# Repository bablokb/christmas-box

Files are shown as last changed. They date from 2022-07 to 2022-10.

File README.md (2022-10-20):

A Christmas-box with sound and display
======================================

This project is about a Christmas-box, that plays a song and
displays images when the lid is opened:

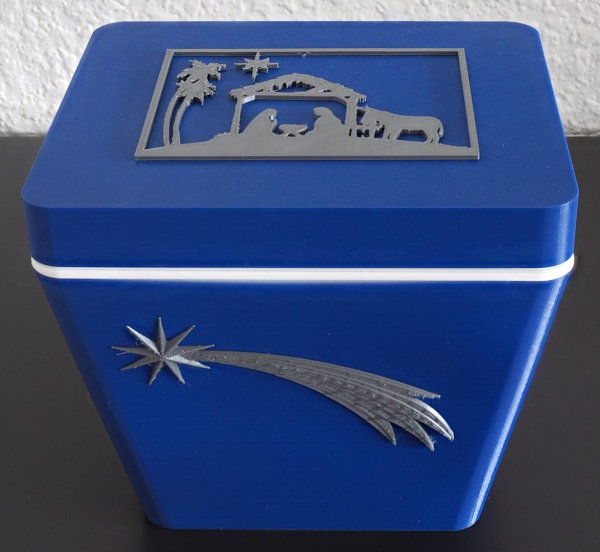
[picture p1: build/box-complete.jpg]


Electronics
-----------

The basis for the electronics is a Raspberry Pi Pico, together
with a small 1.8"-TFT-display and a PAM802A amplifier. The TFT
and the speaker are in the lid, whereas the Pico is inside of
the box.

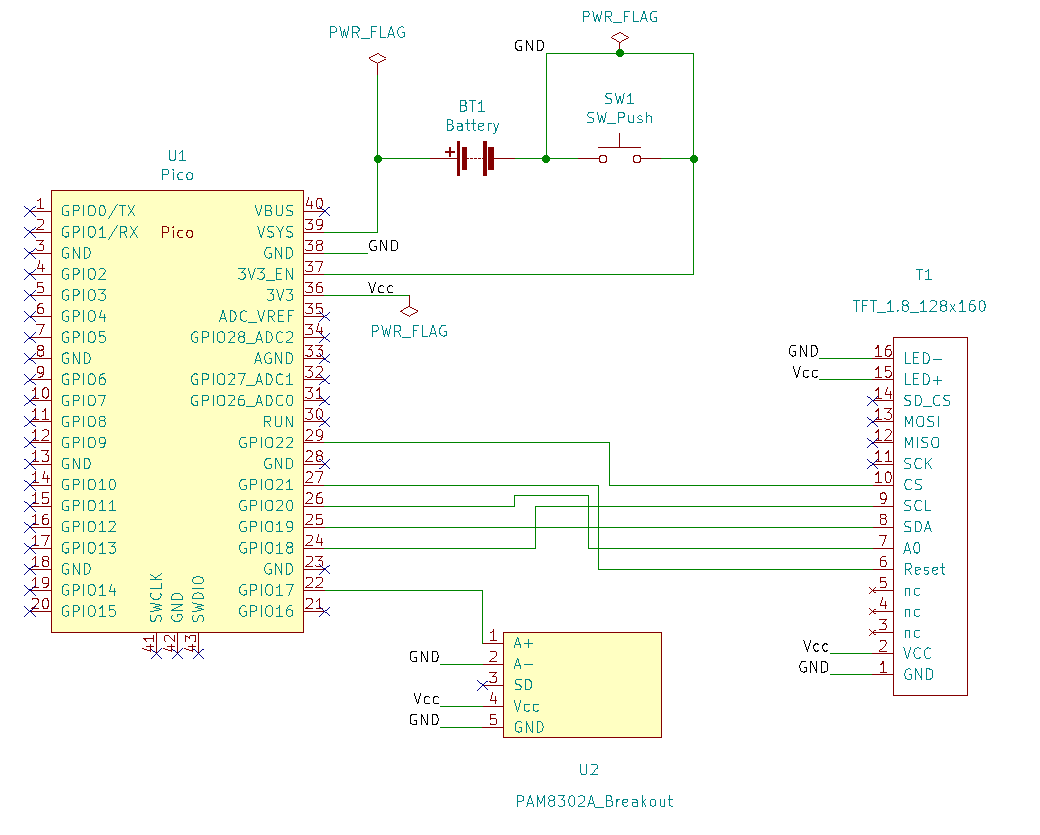
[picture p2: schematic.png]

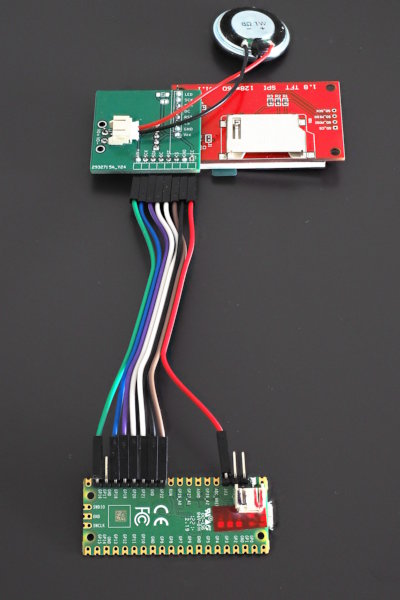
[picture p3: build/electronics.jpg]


(The PAM802A is below the green support PCB).

Software
--------

The Pico runs a small CircuitPython-script that has everything
necessary to display files and to play MP3. The source-code
is in `src/`, some sample media-files are in `src/media/`.

Images must be in BMP-format and the MP3-files are downsampled,
because the Pico does not have enough power to play files with
higher sample-rate.

Build
-----

The box itself was designed using OpenSCAD (source-code in `3D/`).
There is an outer-shell and a smaller inner-shell to make room
for the battery and the Pico:

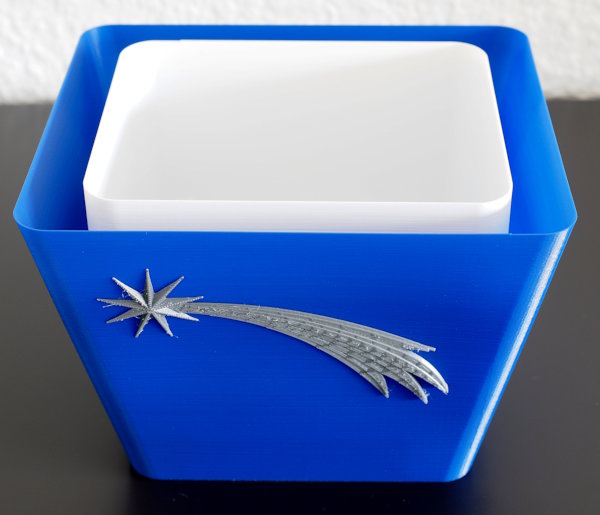
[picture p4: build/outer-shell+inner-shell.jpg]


The lid consists also of two parts:
the outer-part and a frame for the TFT and the speaker.

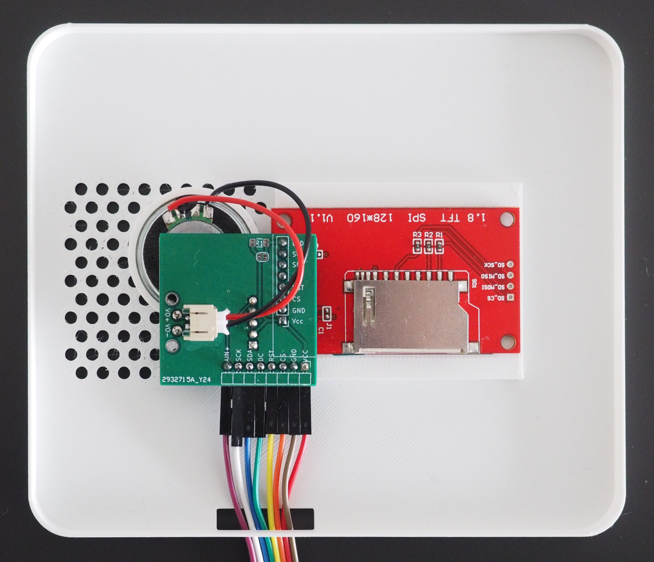
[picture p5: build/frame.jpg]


More images are in the `build/`-directory.

OpenSCAD allows parameters for all dimensions, so you can adjust
the sizes of the parts to your needs without any problems.
Note that I print with tight tolerances, depending on your printer,
you must change this.

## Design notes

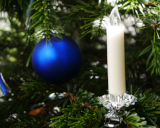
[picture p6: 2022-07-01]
src/media/kugel+kerze.bmp

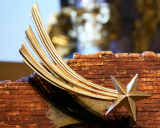
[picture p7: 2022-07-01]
src/media/stern-von-bethlehem.bmp

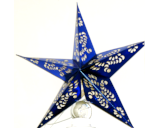
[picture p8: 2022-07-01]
src/media/blauer-stern.bmp

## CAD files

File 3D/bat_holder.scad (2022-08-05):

// -----------------------------------------------------------------------------
// 3D-Model (OpenSCAD) of the battery-holder
//
// Author: Bernhard Bablok
// License: GPL3
//
// https://github.com/bablokb/christmas-box
//
// -----------------------------------------------------------------------------

include <dimensions.scad>

include <BOSL2/std.scad>

module walls() {
  union() {
    translate([0,-y_bat/2,0]) cuboid([2*x_bot,w2,z_bat]);
    translate([0,y_bat/2,0]) cuboid([2*x_bot,w2,z_bat]);
    translate([-x_bat/2,0,0]) cuboid([w2,2*y_bot,z_bat]);
    translate([x_bat/2,0,0]) cuboid([w2,2*y_bot,z_bat]);
  }
}

difference() {
  intersection() {
    translate([0,0,z_bat/2]) walls();
    prismoid(size1=[x_bot-w06,y_bot-w06], 
           size2=[x_top-w06,y_top-w06],
           rounding=10,
           h=z_top+z_b);
  }
  translate([x_bat/2-fuzz,y_bat/2-1.25*c_bat,z_bat/2+c_bat]) cuboid([w2+2*fuzz,c_bat,z_bat]);
  translate([x_bat/2+0.5*(x_bot/2-x_bat/2),-y_bat/2,z_bat/2+c_bat]) cuboid([c_bat,w2+2*fuzz,z_bat]);
}

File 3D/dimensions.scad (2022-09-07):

// -----------------------------------------------------------------------------
// 3D-Model (OpenSCAD) of the christmas-box.
//
// This file defines various dimensions and is included in other scad-scripts.
//
// Author: Bernhard Bablok
// License: GPL3
//
// https://github.com/bablokb/christmas-box
//
// -----------------------------------------------------------------------------

$fa = 1;
$fs = 0.5;
//$fn = 96;

// printer dimensions (walls)

fuzz = 0.01;
gap  = 0.1;
w06 = 0.6;               // vase-mode with wall-thickness 0.6mm
w2  = 0.86;              // 2 walls Prusa MK3S with 0.2mm layer-hight
w4  = 1.67;              // 4 walls Prusa MK3S with 0.2mm layer-hight

// outer shell

x_top = 140;
y_top = 120;
x_del = 18.3;
y_del = 18.3;
x_bot =  x_top - 2*x_del;
y_bot =  y_top - 2*y_del;
z_top =  100;
z_b   =  0.6;            // vase-mode 3 layers
z_lid =  16.5 + z_b;       // inner-hight + base

// inner plate

b_plate = 4.5;
g_leaf  = b_plate - 2.5; // set leaf_gauge of hinges to this value

// hinges

x_hinges     = 30;
y_hinges     =  2;
x_hinges_off = 12;
y_hinges_off = y_top/2 - y_hinges;

// battery dimensions

x_bat = 64.0;
y_bat = 27.0;
z_bat = 19.0;
c_bat = 4.0;     // cutout

// inner shell

x_is = x_bot-w06 + (x_top-x_bot)*(z_bat+z_b)/z_top;  // linear interpolation
y_is = y_bot-w06 + (y_top-y_bot)*(z_bat+z_b)/z_top;  // of dimensions

// frame

x_frame = 100;
y_frame = 60;
b_frame = 0.6;                           // frame-base

// cutout connector

x_conn     = 18;
y_conn     =  5;
x_conn_off = -x_frame/2+55.5;
y_conn_off = y_top/2-w06-w2-y_conn;

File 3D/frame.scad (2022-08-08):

// -----------------------------------------------------------------------------
// 3D-Model (OpenSCAD) of the frame for the display and speaker.
//
// Author: Bernhard Bablok
// License: GPL3
//
// https://github.com/bablokb/christmas-box
//
// -----------------------------------------------------------------------------

include <dimensions.scad>

include <BOSL2/std.scad>

spk_di     = 28.2;                         // speaker, inner diameter
spk_do     = spk_di + 2*w4;                // speaker, outer diameter
spk_off    = 3.0;                          // offset
spk_h      = 4.4;                          // hight

disp_xo     = 58.0;                        // display, outer dimensions
disp_yo     = 46.0;
disp_zo     =  2.9;
disp_off_xo = -(disp_xo+spk_off+spk_do)/2;   // display-offsets
disp_off_yo = -disp_yo/2;

disp_xi     = 44.5;                        // display, innerer dimensions
disp_yi     = 34.2;
disp_zi     =  2.9+b_frame+fuzz;
disp_off_xi = disp_off_xo + 6.9;
disp_off_yi = disp_off_yo + (disp_yo-disp_yi)/2;

disp_pin_x  = 6.9;                         // cutout for display-pins
disp_pin_y  = 23;
disp_pin_z  = 1.3;

spk_grid_x = disp_yo;
spk_grid_y = disp_yo;

// --- supports for display and speaker   ------------------------------------

module supports() {
  cuboid([disp_xo,disp_yo,disp_zo],                    // display-support
          p1=[disp_off_xo,disp_off_yo,b_frame]);   
  translate([disp_off_xo+disp_xo+spk_off+spk_do/2,     // speaker-support
             -(disp_yo-disp_yi)/2,b_frame])
     cylinder(d=spk_do,h=spk_h,center=false);
}

// --- speaker-grid coutouts   -----------------------------------------------

module spk_grid() {
  grid2d(size=[spk_grid_x,spk_grid_y],spacing=5,stagger="alt")
      cylinder(d=3,h=b_frame+fuzz);
}

// --- cutouts for display, speaker, speaker-grid   --------------------------

module cutouts() {
  cuboid([disp_xi,disp_yi,disp_zi],                                  // display
              p1=[disp_off_xi,disp_off_yi,0]);
  cuboid([disp_pin_x,disp_pin_y,disp_pin_z],                         // display-pins
              p1=[disp_off_xi+disp_xi,disp_off_yi+(disp_yi-disp_pin_y)/2,disp_zi-disp_pin_z+fuzz]);
  translate([disp_off_xo+disp_xo+spk_off+spk_di/2+w4,                // speaker
                           -(disp_yo-disp_yi)/2,b_frame])
                   cylinder(d=spk_di,h=spk_h+b_frame+fuzz,center=false);
  translate([disp_off_xo+disp_xo+spk_grid_x/2+spk_off,              // speaker-grid
                           0,0]) spk_grid();
  cuboid([x_conn,y_conn,b_frame+fuzz],
         p1=[x_conn_off,y_conn_off,0]);
}

// --- base-module: plate + wall   --------------------------------------------

module base() {
  prismoid(size1=[x_top,y_top],
           size2=[x_top,y_top],anchor=BOTTOM+CENTER,
           rounding=10,h=b_frame);
  translate([0,0,b_frame]) difference() {
    prismoid(size1=[x_top-2*w06,y_top-2*w06],
             size2=[x_top-2*w06,y_top-2*w06],anchor=BOTTOM+CENTER,
             rounding=10,h=z_lid-z_b-1);
    prismoid(size1=[x_top-2*w06-2*w2,y_top-2*w06-2*w2],
             size2=[x_top-2*w06-2*w2,y_top-2*w06-2*w2],anchor=BOTTOM+CENTER,
             rounding=10,h=z_lid-z_b-1);
  }
}

// --- final frame: base + supports - cutouts   ---------------------------------

module frame() {
  difference() {
    union() {
      base();
      supports();
    }
    cutouts();
  }
}

frame();

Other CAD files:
3D/hinges.scad
3D/inner-plate.scad
3D/inner-shell.scad
3D/lid.scad
3D/pico_holder.scad
3D/shell.scad

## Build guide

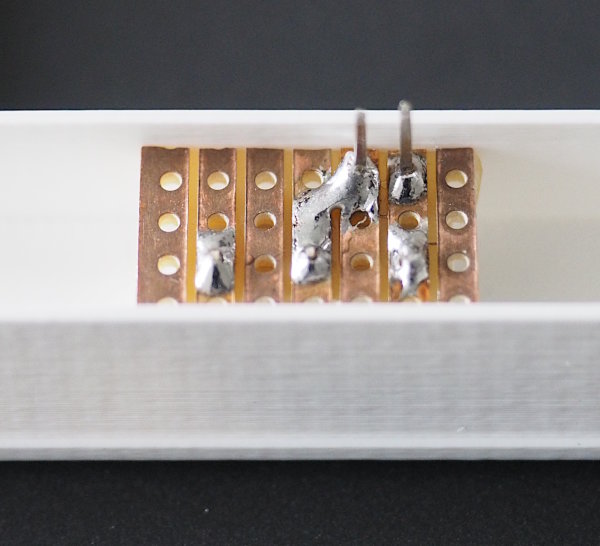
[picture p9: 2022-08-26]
build/button-stripboard.jpg

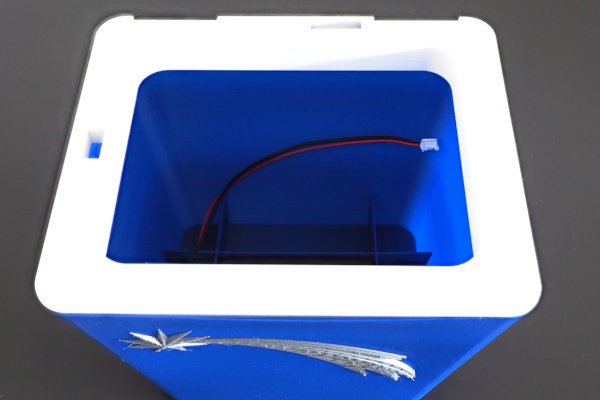
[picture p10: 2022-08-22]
build/outer-shell+inner-plate.jpg

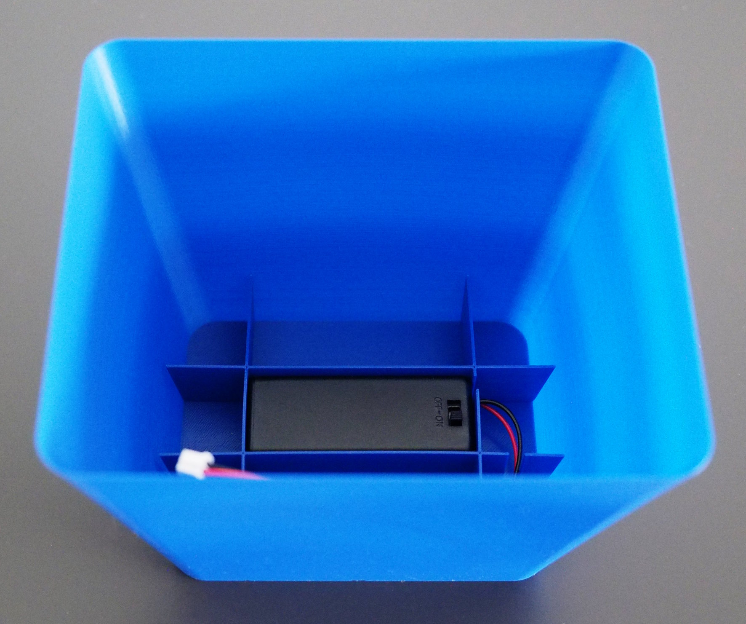
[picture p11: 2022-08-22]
build/outer-shell.jpg

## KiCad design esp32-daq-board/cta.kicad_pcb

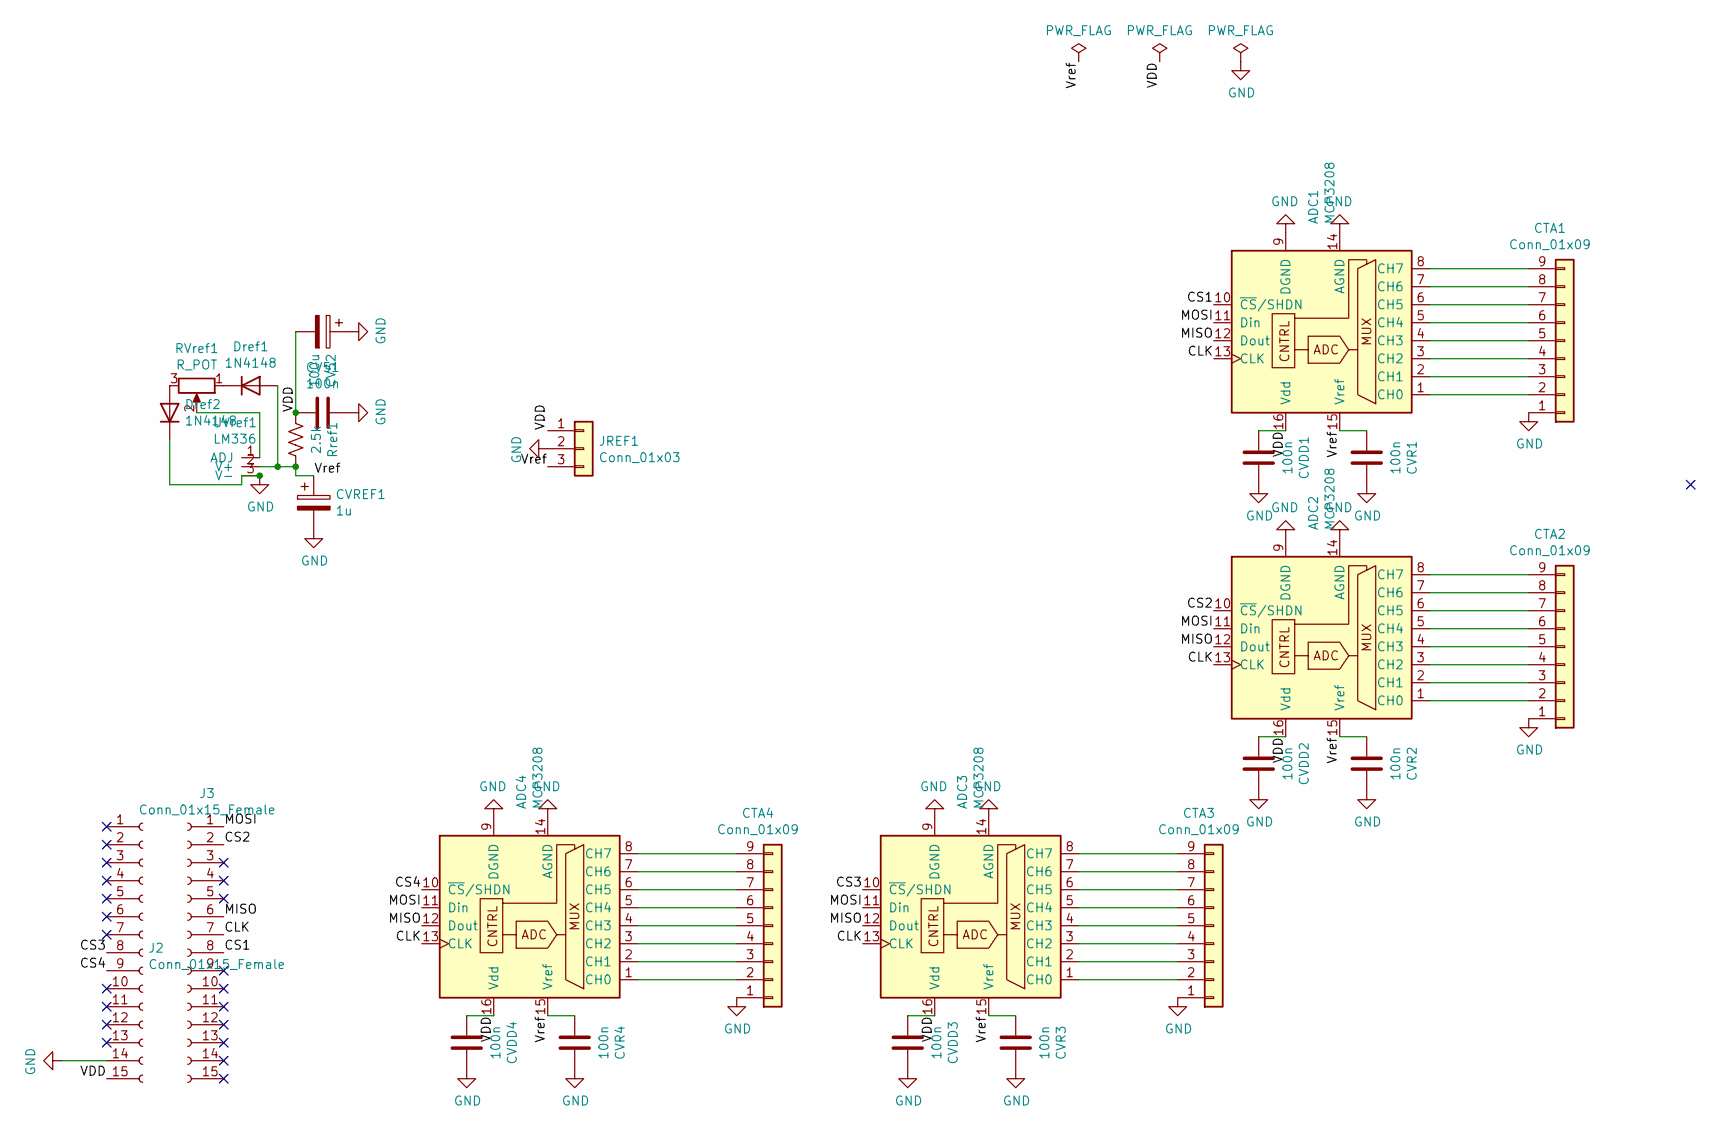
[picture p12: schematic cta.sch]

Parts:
ADC1, ADC2, ADC3, ADC4: MCP3208; DIP-16_W7.62mm_LongPads
CTA1, CTA2, CTA3, CTA4: Conn_01x09; PinHeader_1x09_P2.54mm_Vertical
CV51: 100n; C_Rect_L7.2mm_W3.0mm_P5.00mm_FKS2_FKP2_MKS2_MKP2
CV52: 100u; CP_Radial_D6.3mm_P2.50mm
CVDD1, CVDD2, CVDD3, CVDD4: 100n; C_Rect_L7.2mm_W3.0mm_P5.00mm_FKS2_FKP2_MKS2_MKP2
CVR1, CVR2, CVR3, CVR4: 100n; C_Rect_L7.2mm_W3.0mm_P5.00mm_FKS2_FKP2_MKS2_MKP2
CVREF1: 1u; CP_Radial_D4.0mm_P2.00mm
Dref1, Dref2: 1N4148; D_DO-35_SOD27_P7.62mm_Horizontal
J2, J3: Conn_01x15_Female; PinSocket_1x15_P2.54mm_Vertical
JREF1: Conn_01x03; TerminalBlock_bornier-3_P5.08mm
RVref1: R_POT; Potentiometer_Bourns_3296W_Vertical
Rref1: 2.5k; R_Axial_DIN0207_L6.3mm_D2.5mm_P10.16mm_Horizontal
UVref1: LM336; TO-92L_Inline_Wide

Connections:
/CLK: ADC1.13 (CLK), ADC2.13 (CLK), ADC3.13 (CLK), ADC4.13 (CLK), J3.7
/CS1: ADC1.10 (~CS~/SHDN), J3.8
/CS2: ADC2.10 (~CS~/SHDN), J3.2
/CS3: ADC3.10 (~CS~/SHDN), J2.8
/CS4: ADC4.10 (~CS~/SHDN), J2.9
/MISO: ADC1.12 (Dout), ADC2.12 (Dout), ADC3.12 (Dout), ADC4.12 (Dout), J3.6
/MOSI: ADC1.11 (Din), ADC2.11 (Din), ADC3.11 (Din), ADC4.11 (Din), J3.1
/VDD: ADC1.16 (Vdd), ADC2.16 (Vdd), ADC3.16 (Vdd), ADC4.16 (Vdd), CV51.2, CV52.2, CVDD1.2, CVDD2.2, CVDD3.2, CVDD4.2, J2.15, JREF1.1, Rref1.2
/Vref: ADC1.15 (Vref), ADC2.15 (Vref), ADC3.15 (Vref), ADC4.15 (Vref), CVR1.2, CVR2.2, CVR3.2, CVR4.2, CVREF1.1, Dref1.2 (A), JREF1.3, Rref1.1, UVref1.2 (V+)
GND: ADC1.9 (DGND), ADC1.14 (AGND), ADC2.9 (DGND), ADC2.14 (AGND), ADC3.9 (DGND), ADC3.14 (AGND), ADC4.9 (DGND), ADC4.14 (AGND), CTA1.1, CTA2.1, CTA3.1, CTA4.1, CV51.1, CV52.1, CVDD1.1, CVDD2.1, CVDD3.1, CVDD4.1, CVR1.1, CVR2.1, CVR3.1, CVR4.1, CVREF1.2, Dref2.1 (K), J2.14, JREF1.2, UVref1.3 (V-)
unnamed: ADC1.1 (CH0), CTA1.2
unnamed: ADC1.2 (CH1), CTA1.3
unnamed: ADC1.3 (CH2), CTA1.4
unnamed: ADC1.4 (CH3), CTA1.5
unnamed: ADC1.5 (CH4), CTA1.6
unnamed: ADC1.6 (CH5), CTA1.7
unnamed: ADC1.7 (CH6), CTA1.8
unnamed: ADC1.8 (CH7), CTA1.9
unnamed: ADC2.1 (CH0), CTA2.2
unnamed: ADC2.2 (CH1), CTA2.3
unnamed: ADC2.3 (CH2), CTA2.4
unnamed: ADC2.4 (CH3), CTA2.5
unnamed: ADC2.5 (CH4), CTA2.6
unnamed: ADC2.6 (CH5), CTA2.7
unnamed: ADC2.7 (CH6), CTA2.8
unnamed: ADC2.8 (CH7), CTA2.9
unnamed: ADC3.1 (CH0), CTA3.2
unnamed: ADC3.2 (CH1), CTA3.3
unnamed: ADC3.3 (CH2), CTA3.4
unnamed: ADC3.4 (CH3), CTA3.5
unnamed: ADC3.5 (CH4), CTA3.6
unnamed: ADC3.6 (CH5), CTA3.7
unnamed: ADC3.7 (CH6), CTA3.8
unnamed: ADC3.8 (CH7), CTA3.9
unnamed: ADC4.1 (CH0), CTA4.2
unnamed: ADC4.2 (CH1), CTA4.3
unnamed: ADC4.3 (CH2), CTA4.4
unnamed: ADC4.4 (CH3), CTA4.5
unnamed: ADC4.5 (CH4), CTA4.6
unnamed: ADC4.6 (CH5), CTA4.7
unnamed: ADC4.7 (CH6), CTA4.8
unnamed: ADC4.8 (CH7), CTA4.9
unnamed: Dref1.1 (K), RVref1.1
unnamed: Dref2.2 (A), RVref1.3
unnamed: RVref1.2, UVref1.1 (ADJ)

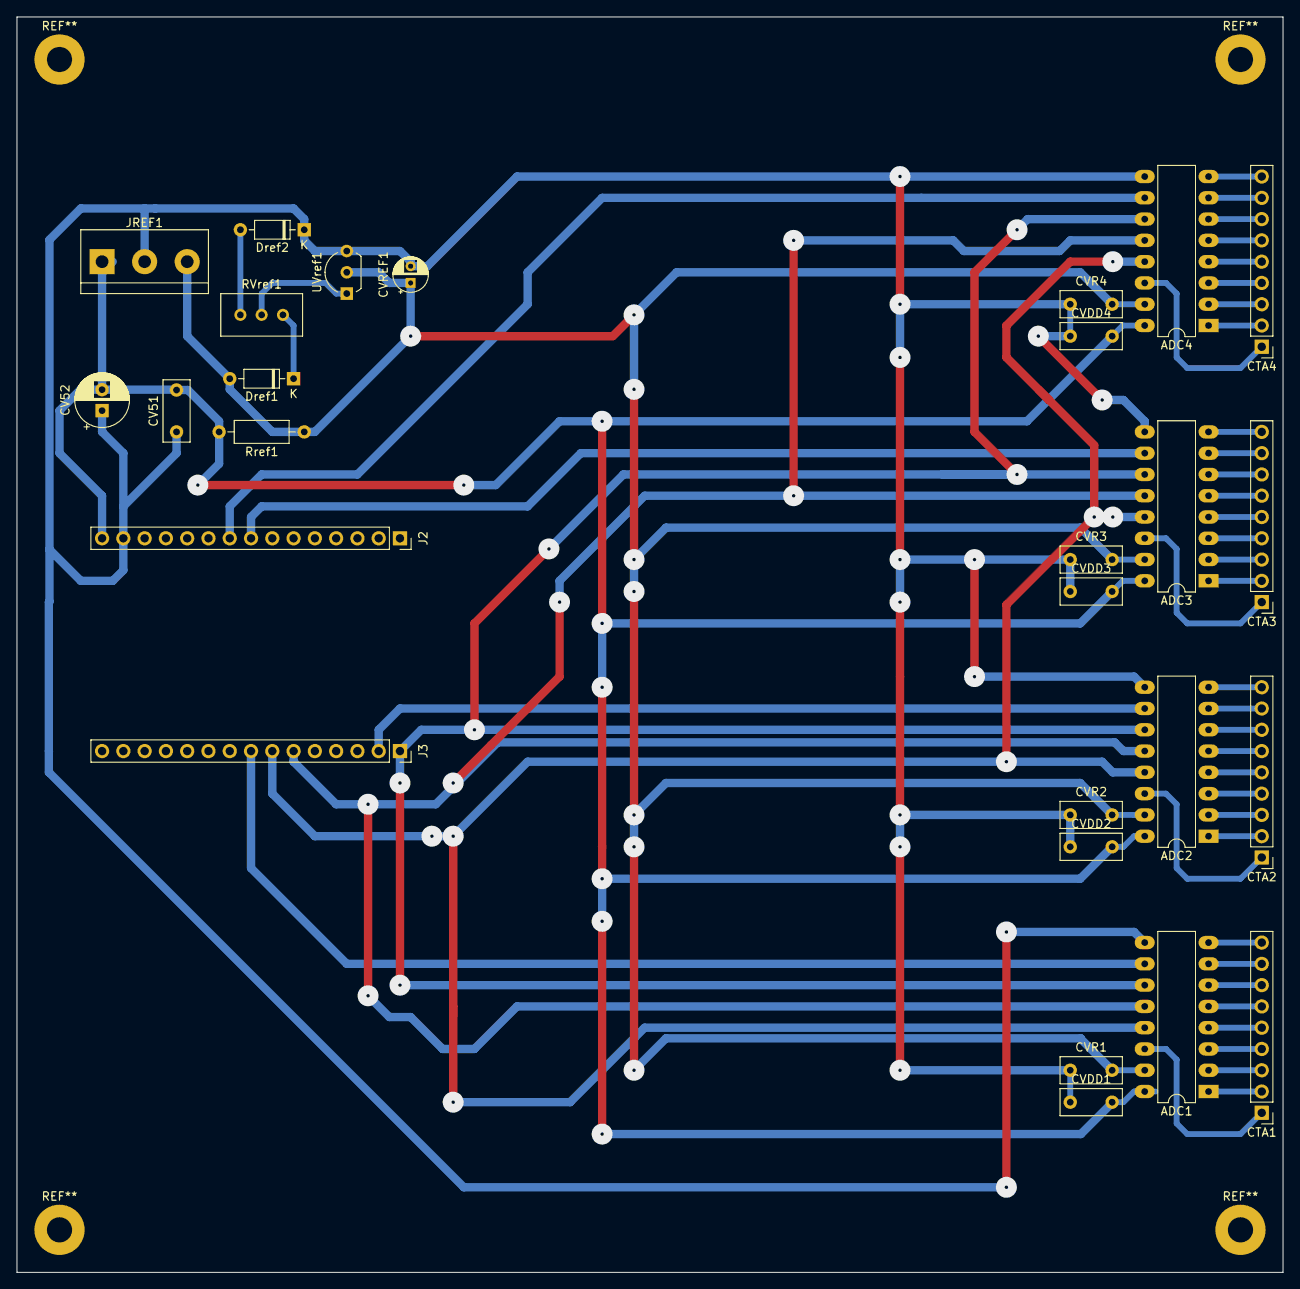
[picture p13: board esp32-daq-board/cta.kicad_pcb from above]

Board: 2 copper layers, 151.1 x 149.9 mm, 27 parts (0 on the bottom side), 45 nets.

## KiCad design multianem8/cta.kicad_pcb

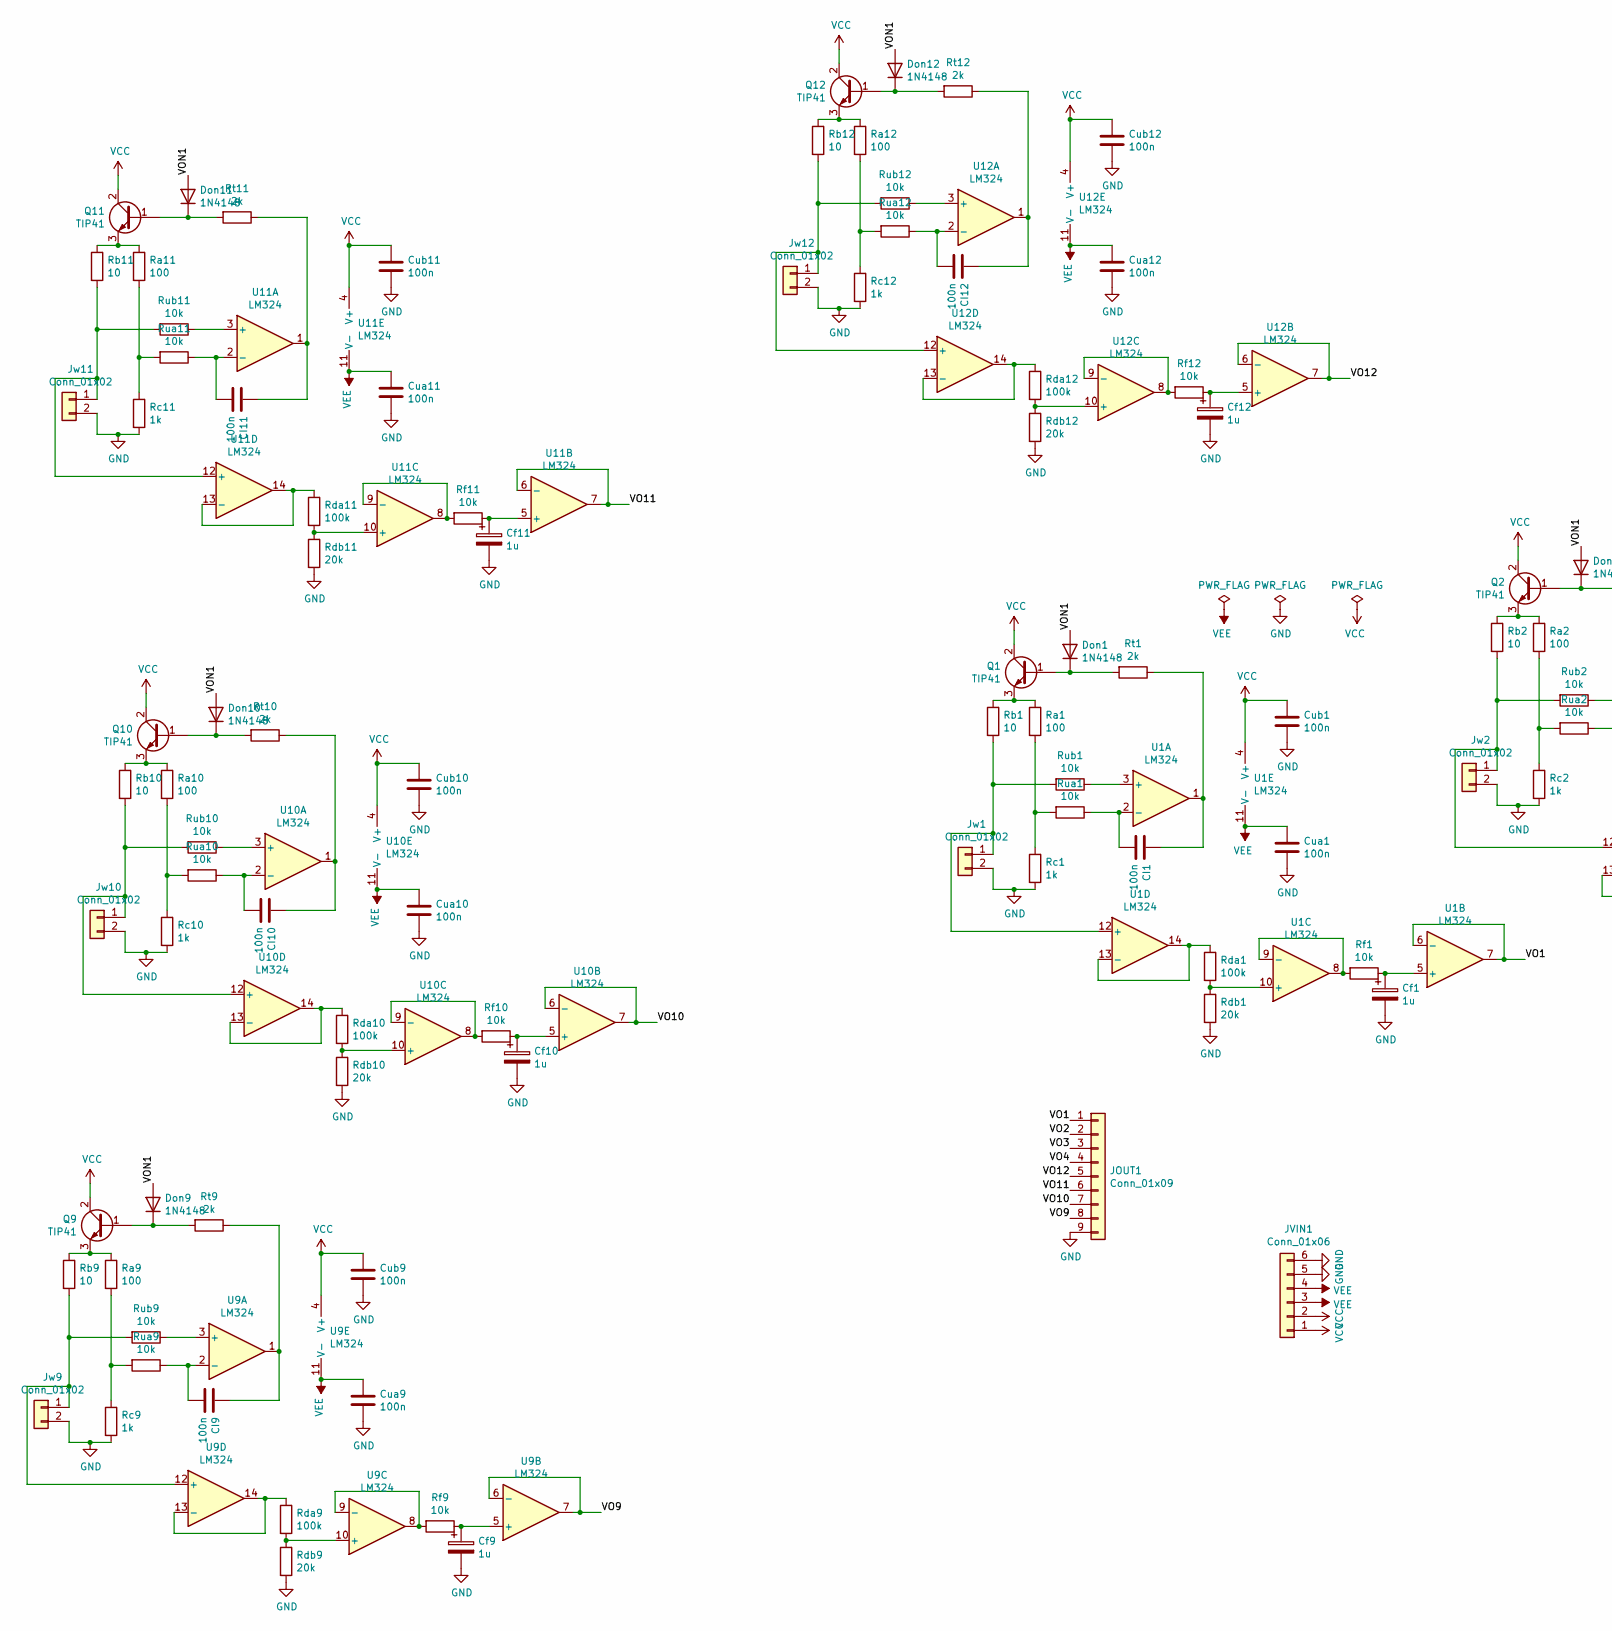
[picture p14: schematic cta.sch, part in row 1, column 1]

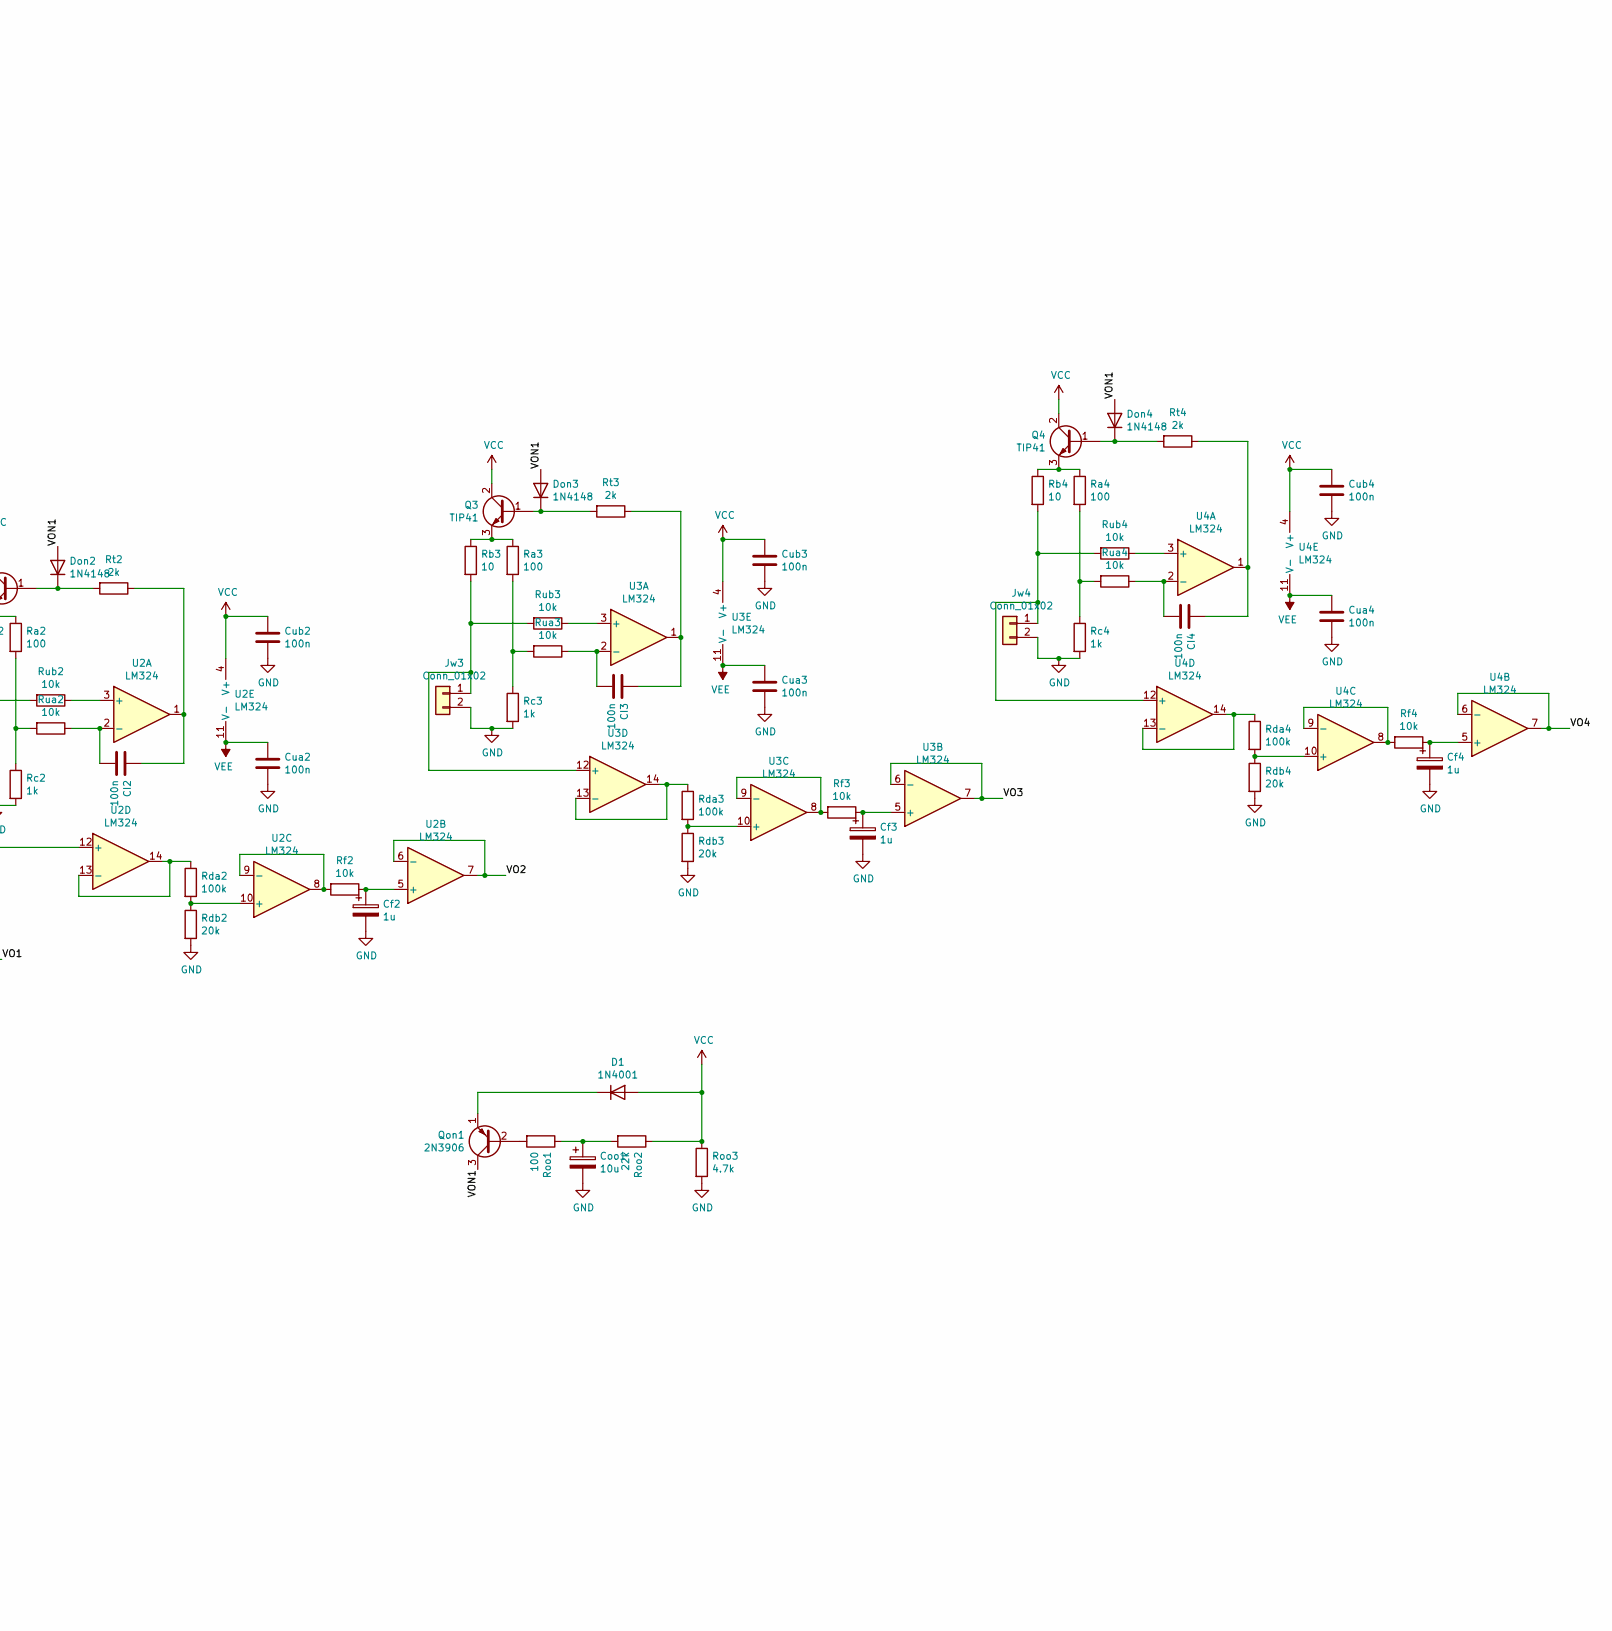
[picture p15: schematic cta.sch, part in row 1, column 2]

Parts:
CI1, CI2, CI3, CI4, CI9, CI10, CI11, CI12: 100n; C_Rect_L7.2mm_W3.5mm_P5.00mm_FKS2_FKP2_MKS2_MKP2
Cf1, Cf2, Cf3, Cf4, Cf9, Cf10, Cf11, Cf12: 1u; CP_Radial_D5.0mm_P2.50mm
Coo1: 10u; CP_Radial_D5.0mm_P2.50mm
Cua1, Cua2, Cua3, Cua4, Cua9, Cua10, Cua11, Cua12: 100n; C_Disc_D5.0mm_W2.5mm_P2.50mm
Cub1, Cub2, Cub3, Cub4, Cub9, Cub10, Cub11, Cub12: 100n; C_Disc_D5.0mm_W2.5mm_P2.50mm
D1: 1N4001; D_DO-41_SOD81_P10.16mm_Horizontal
Don1, Don2, Don3, Don4, Don9, Don10, Don11, Don12: 1N4148; D_DO-35_SOD27_P7.62mm_Horizontal
JOUT1: Conn_01x09; PinHeader_1x09_P2.54mm_Vertical
JVIN1: Conn_01x06; TerminalBlock_bornier-6_P5.08mm
Jw1, Jw2, Jw3, Jw4, Jw9, Jw10, Jw11, Jw12: Conn_01x02; PinHeader_1x02_P2.54mm_Vertical
Q1, Q2, Q3, Q4, Q9, Q10, Q11, Q12: TIP41; TO-220-3_Vertical
Qon1: 2N3906; TO-92_Inline_Wide
Ra1, Ra2, Ra3, Ra4, Ra9, Ra10, Ra11, Ra12: 100; R_Axial_DIN0207_L6.3mm_D2.5mm_P10.16mm_Horizontal
Rb1, Rb2, Rb3, Rb4, Rb9, Rb10, Rb11, Rb12: 10; R_Axial_DIN0414_L11.9mm_D4.5mm_P15.24mm_Horizontal
Rc1, Rc2, Rc3, Rc4, Rc9, Rc10, Rc11, Rc12: 1k; R_Axial_DIN0207_L6.3mm_D2.5mm_P10.16mm_Horizontal
Rda1, Rda2, Rda3, Rda4, Rda9, Rda10, Rda11, Rda12: 100k; R_Axial_DIN0207_L6.3mm_D2.5mm_P10.16mm_Horizontal
Rdb1, Rdb2, Rdb3, Rdb4, Rdb9, Rdb10, Rdb11, Rdb12: 20k; R_Axial_DIN0207_L6.3mm_D2.5mm_P10.16mm_Horizontal
Rf1, Rf2, Rf3, Rf4, Rf9, Rf10, Rf11, Rf12: 10k; R_Axial_DIN0207_L6.3mm_D2.5mm_P10.16mm_Horizontal
Roo1: 100; R_Axial_DIN0207_L6.3mm_D2.5mm_P10.16mm_Horizontal
Roo2: 22k; R_Axial_DIN0207_L6.3mm_D2.5mm_P10.16mm_Horizontal
Roo3: 4.7k; R_Axial_DIN0207_L6.3mm_D2.5mm_P10.16mm_Horizontal
Rt1, Rt2, Rt3, Rt4, Rt9, Rt10, Rt11, Rt12: 2k; R_Axial_DIN0207_L6.3mm_D2.5mm_P10.16mm_Horizontal
Rua1, Rua2, Rua3, Rua4, Rua9, Rua10, Rua11, Rua12: 10k; R_Axial_DIN0207_L6.3mm_D2.5mm_P10.16mm_Horizontal
Rub1, Rub2, Rub3, Rub4, Rub9, Rub10, Rub11, Rub12: 10k; R_Axial_DIN0207_L6.3mm_D2.5mm_P10.16mm_Horizontal
U1, U2, U3, U4, U9, U10, U11, U12: LM324; DIP-14_W7.62mm_LongPads

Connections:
/VO1: JOUT1.1, U1.6 (-), U1.7
/VO2: JOUT1.2, U2.6 (-), U2.7
/VO3: JOUT1.3, U3.6 (-), U3.7
/VO4: JOUT1.4, U4.6 (-), U4.7
/VO9: JOUT1.8, U9.6 (-), U9.7
/VO10: JOUT1.7, U10.6 (-), U10.7
/VO11: JOUT1.6, U11.6 (-), U11.7
/VO12: JOUT1.5, U12.6 (-), U12.7
/VON1: Don1.2 (A), Don2.2 (A), Don3.2 (A), Don4.2 (A), Don9.2 (A), Don10.2 (A), Don11.2 (A), Don12.2 (A), Qon1.3 (C)
GND: Cf1.2, Cf2.2, Cf3.2, Cf4.2, Cf9.2, Cf10.2, Cf11.2, Cf12.2, Coo1.2, Cua1.2, Cua2.2, Cua3.2, Cua4.2, Cua9.2, Cua10.2, Cua11.2, Cua12.2, Cub1.2, Cub2.2, Cub3.2, Cub4.2, Cub9.2, Cub10.2, Cub11.2, Cub12.2, JOUT1.9, JVIN1.5, JVIN1.6, Jw1.2, Jw2.2, Jw3.2, Jw4.2, Jw9.2, Jw10.2, Jw11.2, Jw12.2, Rc1.2, Rc2.2, Rc3.2, Rc4.2, Rc9.2, Rc10.2, Rc11.2, Rc12.2, Rdb1.2, Rdb2.2, Rdb3.2, Rdb4.2, Rdb9.2, Rdb10.2, Rdb11.2, Rdb12.2, Roo3.2
unnamed: CI1.1, Rt1.1, U1.1
unnamed: CI1.2, Rua1.1, U1.2 (-)
unnamed: CI2.1, Rt2.1, U2.1
unnamed: CI2.2, Rua2.1, U2.2 (-)
unnamed: CI3.1, Rt3.1, U3.1
unnamed: CI3.2, Rua3.1, U3.2 (-)
unnamed: CI4.1, Rt4.1, U4.1
unnamed: CI4.2, Rua4.1, U4.2 (-)
unnamed: CI9.1, Rt9.1, U9.1
unnamed: CI9.2, Rua9.1, U9.2 (-)
unnamed: CI10.1, Rt10.1, U10.1
unnamed: CI10.2, Rua10.1, U10.2 (-)
unnamed: CI11.1, Rt11.1, U11.1
unnamed: CI11.2, Rua11.1, U11.2 (-)
unnamed: CI12.1, Rt12.1, U12.1
unnamed: CI12.2, Rua12.1, U12.2 (-)
unnamed: Cf1.1, Rf1.1, U1.5 (+)
unnamed: Cf2.1, Rf2.1, U2.5 (+)
unnamed: Cf3.1, Rf3.1, U3.5 (+)
unnamed: Cf4.1, Rf4.1, U4.5 (+)
unnamed: Cf9.1, Rf9.1, U9.5 (+)
unnamed: Cf10.1, Rf10.1, U10.5 (+)
unnamed: Cf11.1, Rf11.1, U11.5 (+)
unnamed: Cf12.1, Rf12.1, U12.5 (+)
unnamed: Coo1.1, Roo1.1, Roo2.2
unnamed: D1.1 (K), Qon1.1 (E)
unnamed: Don1.1 (K), Q1.1 (B), Rt1.2
unnamed: Don2.1 (K), Q2.1 (B), Rt2.2
unnamed: Don3.1 (K), Q3.1 (B), Rt3.2
unnamed: Don4.1 (K), Q4.1 (B), Rt4.2
unnamed: Don9.1 (K), Q9.1 (B), Rt9.2
unnamed: Don10.1 (K), Q10.1 (B), Rt10.2
unnamed: Don11.1 (K), Q11.1 (B), Rt11.2
unnamed: Don12.1 (K), Q12.1 (B), Rt12.2
unnamed: Jw1.1, Rb1.2, Rub1.2, U1.12 (+)
unnamed: Jw2.1, Rb2.2, Rub2.2, U2.12 (+)
unnamed: Jw3.1, Rb3.2, Rub3.2, U3.12 (+)
unnamed: Jw4.1, Rb4.2, Rub4.2, U4.12 (+)
unnamed: Jw9.1, Rb9.2, Rub9.2, U9.12 (+)
unnamed: Jw10.1, Rb10.2, Rub10.2, U10.12 (+)
unnamed: Jw11.1, Rb11.2, Rub11.2, U11.12 (+)
unnamed: Jw12.1, Rb12.2, Rub12.2, U12.12 (+)
unnamed: Q1.3 (E), Ra1.1, Rb1.1
unnamed: Q2.3 (E), Ra2.1, Rb2.1
unnamed: Q3.3 (E), Ra3.1, Rb3.1
unnamed: Q4.3 (E), Ra4.1, Rb4.1
unnamed: Q9.3 (E), Ra9.1, Rb9.1
unnamed: Q10.3 (E), Ra10.1, Rb10.1
unnamed: Q11.3 (E), Ra11.1, Rb11.1
unnamed: Q12.3 (E), Ra12.1, Rb12.1
unnamed: Qon1.2 (B), Roo1.2
unnamed: Ra1.2, Rc1.1, Rua1.2
unnamed: Ra2.2, Rc2.1, Rua2.2
unnamed: Ra3.2, Rc3.1, Rua3.2
unnamed: Ra4.2, Rc4.1, Rua4.2
unnamed: Ra9.2, Rc9.1, Rua9.2
unnamed: Ra10.2, Rc10.1, Rua10.2
unnamed: Ra11.2, Rc11.1, Rua11.2
unnamed: Ra12.2, Rc12.1, Rua12.2
unnamed: Rda1.1, U1.13 (-), U1.14
unnamed: Rda1.2, Rdb1.1, U1.10 (+)
unnamed: Rda2.1, U2.13 (-), U2.14
unnamed: Rda2.2, Rdb2.1, U2.10 (+)
unnamed: Rda3.1, U3.13 (-), U3.14
unnamed: Rda3.2, Rdb3.1, U3.10 (+)
unnamed: Rda4.1, U4.13 (-), U4.14
unnamed: Rda4.2, Rdb4.1, U4.10 (+)
unnamed: Rda9.1, U9.13 (-), U9.14
unnamed: Rda9.2, Rdb9.1, U9.10 (+)
unnamed: Rda10.1, U10.13 (-), U10.14
unnamed: Rda10.2, Rdb10.1, U10.10 (+)
unnamed: Rda11.1, U11.13 (-), U11.14
unnamed: Rda11.2, Rdb11.1, U11.10 (+)
unnamed: Rda12.1, U12.13 (-), U12.14
unnamed: Rda12.2, Rdb12.1, U12.10 (+)
unnamed: Rf1.2, U1.8, U1.9 (-)
unnamed: Rf2.2, U2.8, U2.9 (-)
unnamed: Rf3.2, U3.8, U3.9 (-)
unnamed: Rf4.2, U4.8, U4.9 (-)
unnamed: Rf9.2, U9.8, U9.9 (-)
unnamed: Rf10.2, U10.8, U10.9 (-)
unnamed: Rf11.2, U11.8, U11.9 (-)
unnamed: Rf12.2, U12.8, U12.9 (-)
unnamed: Rub1.1, U1.3 (+)
unnamed: Rub2.1, U2.3 (+)
unnamed: Rub3.1, U3.3 (+)
unnamed: Rub4.1, U4.3 (+)
unnamed: Rub9.1, U9.3 (+)
unnamed: Rub10.1, U10.3 (+)
unnamed: Rub11.1, U11.3 (+)
unnamed: Rub12.1, U12.3 (+)
VCC: Cub1.1, Cub2.1, Cub3.1, Cub4.1, Cub9.1, Cub10.1, Cub11.1, Cub12.1, D1.2 (A), JVIN1.1, JVIN1.2, Q1.2 (C), Q2.2 (C), Q3.2 (C), Q4.2 (C), Q9.2 (C), Q10.2 (C), Q11.2 (C), Q12.2 (C), Roo2.1, Roo3.1, U1.4 (V+), U2.4 (V+), U3.4 (V+), U4.4 (V+), U9.4 (V+), U10.4 (V+), U11.4 (V+), U12.4 (V+)
VEE: Cua1.1, Cua2.1, Cua3.1, Cua4.1, Cua9.1, Cua10.1, Cua11.1, Cua12.1, JVIN1.3, JVIN1.4, U1.11 (V-), U2.11 (V-), U3.11 (V-), U4.11 (V-), U9.11 (V-), U10.11 (V-), U11.11 (V-), U12.11 (V-)

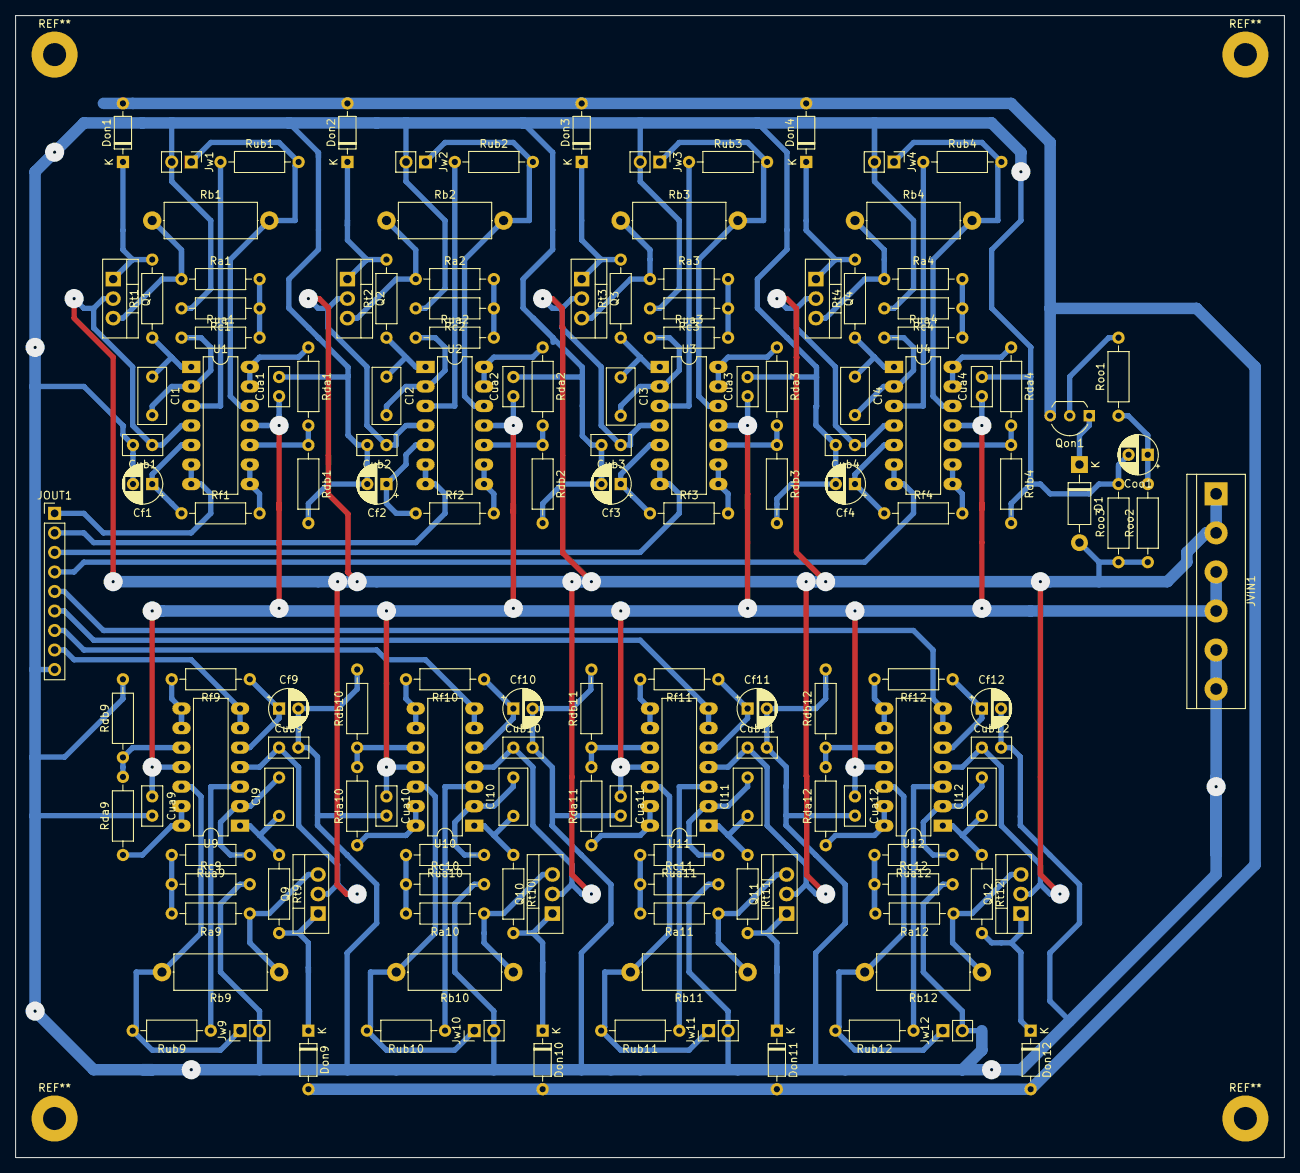
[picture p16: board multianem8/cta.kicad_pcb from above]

Board: 2 copper layers, 165.1 x 148.6 mm, 144 parts (0 on the bottom side), 103 nets.

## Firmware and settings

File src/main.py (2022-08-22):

# ----------------------------------------------------------------------------
# main.py: driver program for the christmas-box.
#
# The program displays the listed images and plays the given mp3.
# Images and sound-files should be in directory ./media
# Note that the mp3-files should be 8k-mono, while the image-files should
# be 160x128 BMPs.
#
# Author: Bernhard Bablok
# License: GPL3
#
# Website: https://github.com/bablokb/christmas-box
#
# ----------------------------------------------------------------------------

import board
import time
import busio
import displayio

from adafruit_st7735r import ST7735R       # SPI-TFT  display

import audiomp3
import audiopwmio

# --- constants - adapt to your needs!   -------------------------------------

PIN_CS   = board.GP22
PIN_RST  = board.GP21
PIN_DC   = board.GP20   # A0 on some displays
PIN_MOSI = board.GP19   # SDA
PIN_CLK  = board.GP18   # SCK
PIN_PWM  = board.GP17   # AIN+ on PAM8302A

TFT_WIDTH  = 160
TFT_HEIGHT = 128
TFT_ROTATE =  90
TFT_BGR    = True

IMG_FILES = [
  'stern-von-bethlehem.bmp',
  'kugel+kerze.bmp',
  'blauer-stern.bmp'
  ]

SND_FILES = [
  'stille-nacht.mp3',
  'o-tannenbaum.mp3'
  ]

# --- create display   -------------------------------------------------------

displayio.release_displays()

spi     = busio.SPI(clock=PIN_CLK,MOSI=PIN_MOSI)
bus     = displayio.FourWire(spi,command=PIN_DC,chip_select=PIN_CS,
                         reset=PIN_RST)
display = ST7735R(bus,width=TFT_WIDTH,height=TFT_HEIGHT,
                 rotation=TFT_ROTATE,bgr=TFT_BGR)
display.auto_refresh = False

group = displayio.Group()

# --- update image   ---------------------------------------------------------

def upd_image(img):
  img_file = open("./media/"+img, "rb")
  bmp  = displayio.OnDiskBitmap(img_file)
  tile = displayio.TileGrid(bmp,pixel_shader=displayio.ColorConverter())
 
  if len(group) == 1:
    del group[0]
  group.append(tile)
  display.show(group)
  display.refresh()

# --- main loop   ------------------------------------------------------------

audio   = audiopwmio.PWMAudioOut(PIN_PWM)
decoder = audiomp3.MP3Decoder(open("./media/"+SND_FILES[0], "rb"))

img_len = len(IMG_FILES)
img_ind = 0
upd_image(IMG_FILES[img_ind])
end_time = time.monotonic() + 5

while True:
  for snd in SND_FILES:
    # play current sound-file
    decoder.file = open("./media/"+snd, "rb")
    audio.play(decoder)

    # show images while playing
    while audio.playing:
      while time.monotonic() < end_time and audio.playing:
        time.sleep(0.1)
      if audio.playing:
        img_ind = (img_ind+1) % img_len
        upd_image(IMG_FILES[img_ind])
        end_time = time.monotonic() + 5

    # close sound-file
    decoder.file.close()

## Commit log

2022-07-28 replaced footprint for JST-connector THT->SMD
    [tft_pam_support.kicad_pcb, tft_pam_support.kicad_sch]
2022-08-05 refactored bat-holder dimensions to dimensions.scad
    [bat_holder.scad, dimensions.scad]
2022-08-05 renamed h_top to z_top
    [bat_holder.scad, dimensions.scad, shell.scad]
2022-08-08 create top-size frame
    [frame.scad]
2022-08-08 refactored dimension-constants to dimensions.scad
    [dimensions.scad, frame.scad]
2022-08-14 added dimensions for inner-shell
    [dimensions.scad]
2022-08-18 added dimensions for inner-plate
    [dimensions.scad]
2022-08-22 bugfix: interrupt image-playback after end of sound-file
    [main.py]
2022-09-06 add thickness
    [dimensions.scad, hinges.scad, inner-plate.scad]
2022-09-07 fix defs for hinges
    [dimensions.scad]
2022-09-07 fix y-dimension of hinges
    [inner-plate.scad]
2023-02-25 fixed size
    [inner-shell.scad]
